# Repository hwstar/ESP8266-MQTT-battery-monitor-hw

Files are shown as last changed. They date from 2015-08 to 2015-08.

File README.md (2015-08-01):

**ESP8266-MQTT-battery-monitor-hw**
==========
This is the hardware implementation for my ESP8266-MQTT-battery-monitor project.

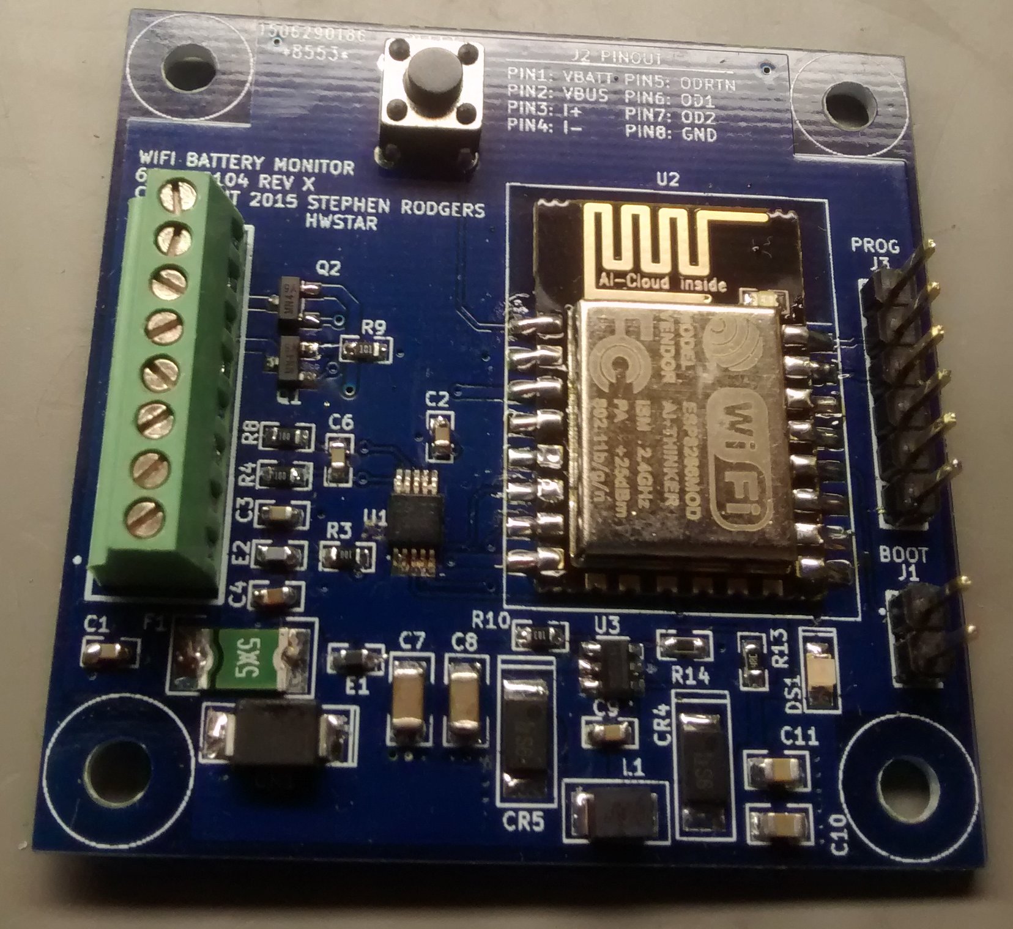
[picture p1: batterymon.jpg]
ProjectPicture


**Features:**

This board contains an ESP12 module, a Texas Instruments LMR12010X DC-DC converter and an Texas Instruments INA226 DC voltage and current monitor.
The board can be powered from any voltage from 5.5V to 16V. It is optimized to work with 12V lead acid batteries. There is transient protection
on the power input, and voltage and current inputs. There is a 1/2 amp PTC fuse on the power input.

A wide range of current shunts can be used on the differential current inputs, and the shunt
current and full scale millivolt values are programmable in the firmware. The current value is and integer, and will be negative if the battery is being discharged.

**EDA Software**

This board was designed using KICAD. 

**Board Size**

5cm x 5cm

**Firmware**

The firmware for this project can be found [here](https://github.com/hwstar/ESP8266-MQTT-battery-monitor-fw)

**LICENSE**

Creative Commons Attribution Share-Alike license. (CC-BY-SA)

**Disclaimer**

Build and use at your own risk. I will not be responsible for any damages including but not limited to: errors or omissions, loss of life, or property damage. You have been warned.

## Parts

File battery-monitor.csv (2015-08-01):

Item | Part Number | Qty | Reference(s) | Title/Description | Value on Schematic | Manufacturer | Manufacturer Part Number
1 | 800000-103 | 3 | C1,C3,C9 | CAP,0603,0.01u,25V,X7R | 0.01u | Open Market | N/A
2 | 800004-106 | 2 | C10,C11 | CAP,0805,10u,16V,X7R | 10u | Samsung | CL21B106KOQNNNE
3 | 800000-104 | 3 | C2,C4,C5 | CAP,0603,0.1u,25V,X7R | 0.1u | Open Market | N/A
4 | 800000-224 | 1 | C6 | CAP,0603,0.22u,25V,X7R | 0.22u | Open Market | N/A
5 | 800005-106 | 2 | C7,C8 | CAP,1206,10u,25V,X7R | 10u | Taiyo-Yuden | TMK316B7106KL-TD
6 | 800141-018 | 1 | CR1 | DIODE,TVS,SMB,18V | SMBJ18 | Littelfuse | SMBJ18A
7 | 800135-024 | 2 | CR2,CR3 | DIODE,DUAL,TVS,SOT23,24V,300W,CA | SM24T1G | On Semiconductor | SM24T1G
8 | 800138-101 | 2 | CR4,CR5 | DIODE,SCHOTTKY,2A,30V,M-FLAT | CMS06 | Toshiba | CMS06
9 | 800113-102 | 1 | DS1 | LED,GREEN,0805 | LEDGRN | Open Market | N/A
10 | 800040-600 | 2 | E1,E2 | FERRITE,CHIP,0603,600 OHM,500MA | FB0603 | TDK | MMZ1608S601A
11 | 800140-500 | 1 | F1 | FUSE,PTC,1812,500mA,24V | 0.5A | Tyco Electronics | MINISMDC050F-2
12 | 800116-102 | 1 | J1 | CONN,HDR,2CKT,0.1PITCH,BERGSTRIP | CONN2 | Open Market | N/A
13 | 800117-108 | 1 | J2 | CONN,TERM BLK,8CKT,0.1 PITCH | CONN8 | Open Market | N/A
14 | 800116-106 | 1 | J3 | CONN,HDR,6CKT,0.1PITCH,BERGSTRIP | CONN6 | Open Market | N/A
15 | 800139-100 | 1 | L1 | IND,1210,10uH,450mA | 10uH | TDK | NLCV32T-100K-PFR
16 | 800123-101 | 2 | Q1,Q2 | XSTR,MOSFET,N-CH,4.0A,30V,SOT-23 | DMN3112 | Diodes Inc. | DMN3112S-7
16 |  |  |  |  |  | Vishay | SI2306BDS-T1-E3
17 | 800010-102 | 5 | R1,R2,R7,R11,R12 | RES,0603,1K OHM,5% | 1K | Open Market | N/A
18 | 800010-103 | 1 | R10 | RES,0603,10K OHM,5% | 10K | Open Market | N/A
19 | 800023-309 | 1 | R13 | RES,0603,30.9K OHM,1% | 30.9K | Open Market | N/A
20 | 800023-100 | 1 | R14 | RES,0603,10.0K OHM,1% | 10.0K | Open Market | N/A
21 | 800011-221 | 1 | R15 | RES,0805,220 OHM,5% | 220 | Open Market | N/A
22 | 800010-100 | 3 | R3,R4,R8 | RES,0603,10 OHM,5% | 10 | Open Market | N/A
23 | 800010-472 | 2 | R5,R6 | RES,0603,4.7K OHM,5% | 4.7K | Open Market | N/A
24 | 800010-101 | 1 | R9 | RES,0603,100 OHM,5% | 100 | Open Market | N/A
25 | 800107-101 | 1 | S1 | SWITCH, TACT, 6MM | SW_TACT | Open Market | N/A
26 | 800137-101 | 1 | U1 | IC,MONITOR,POWER,I2C,BIDIR,10-MSOP | INA226 | Texas Instruments | INA226AIDGSR
27 | 800106-101 | 1 | U2 | MODULE,WIFI,ESP12 | ESP8266-ESP-12 | Open Market | N/A
28 | 800136-101 | 1 | U3 | IC,VREG,SWITCHING,1.6 MHZ,1A,SOT23-6 THIN | LMR12010XMKE | Texas Instruments | LMR12010XMKE/NOPB

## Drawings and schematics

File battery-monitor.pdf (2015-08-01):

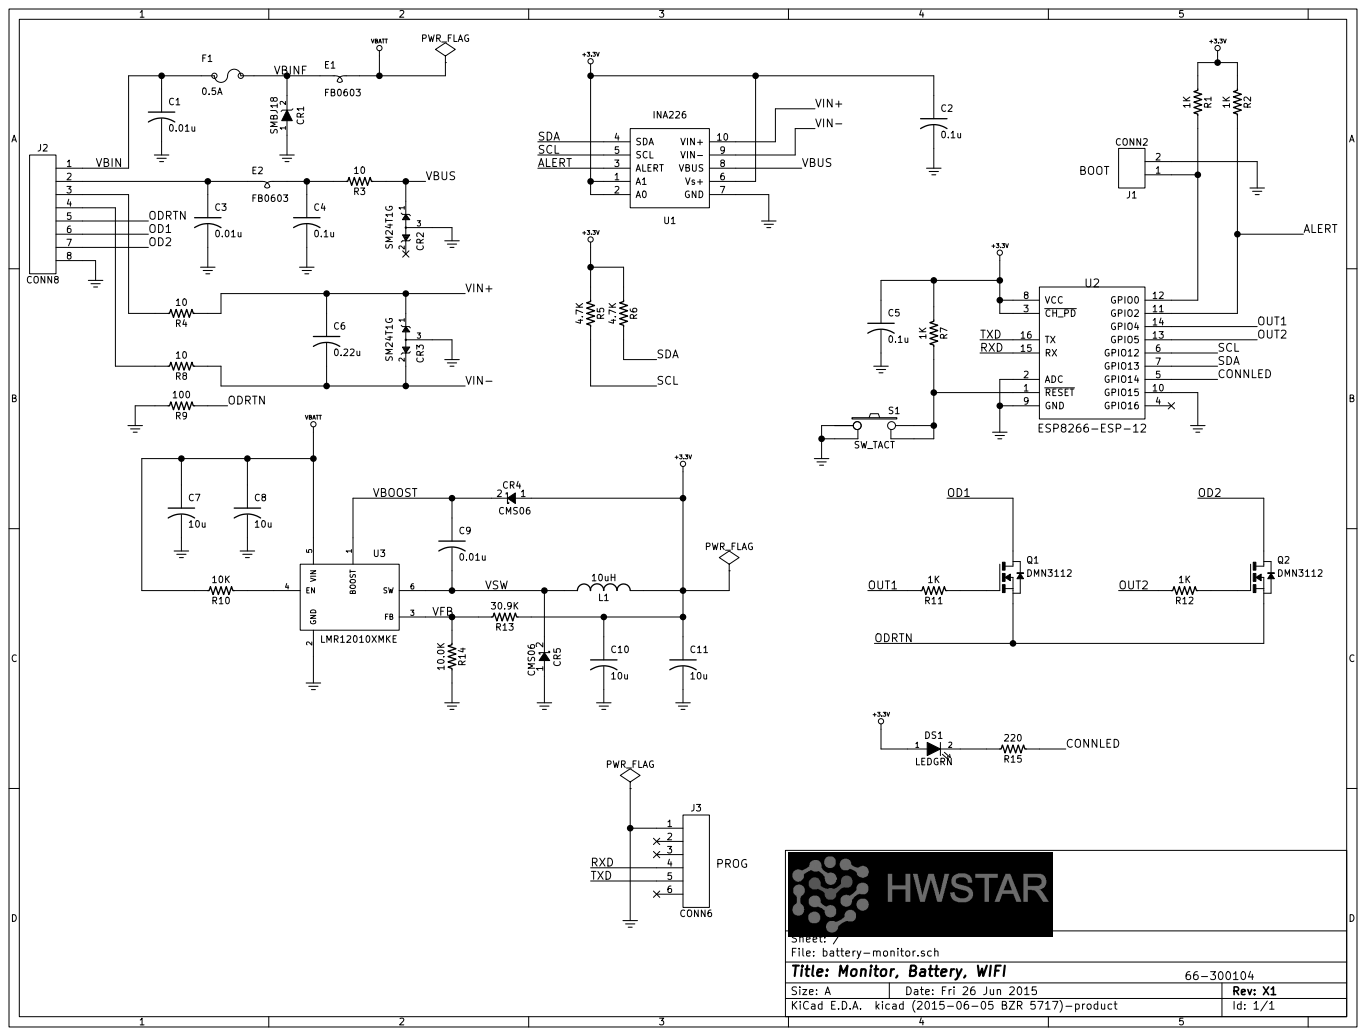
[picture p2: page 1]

Id: 1/1 Title: Monitor, Battery, WIFI

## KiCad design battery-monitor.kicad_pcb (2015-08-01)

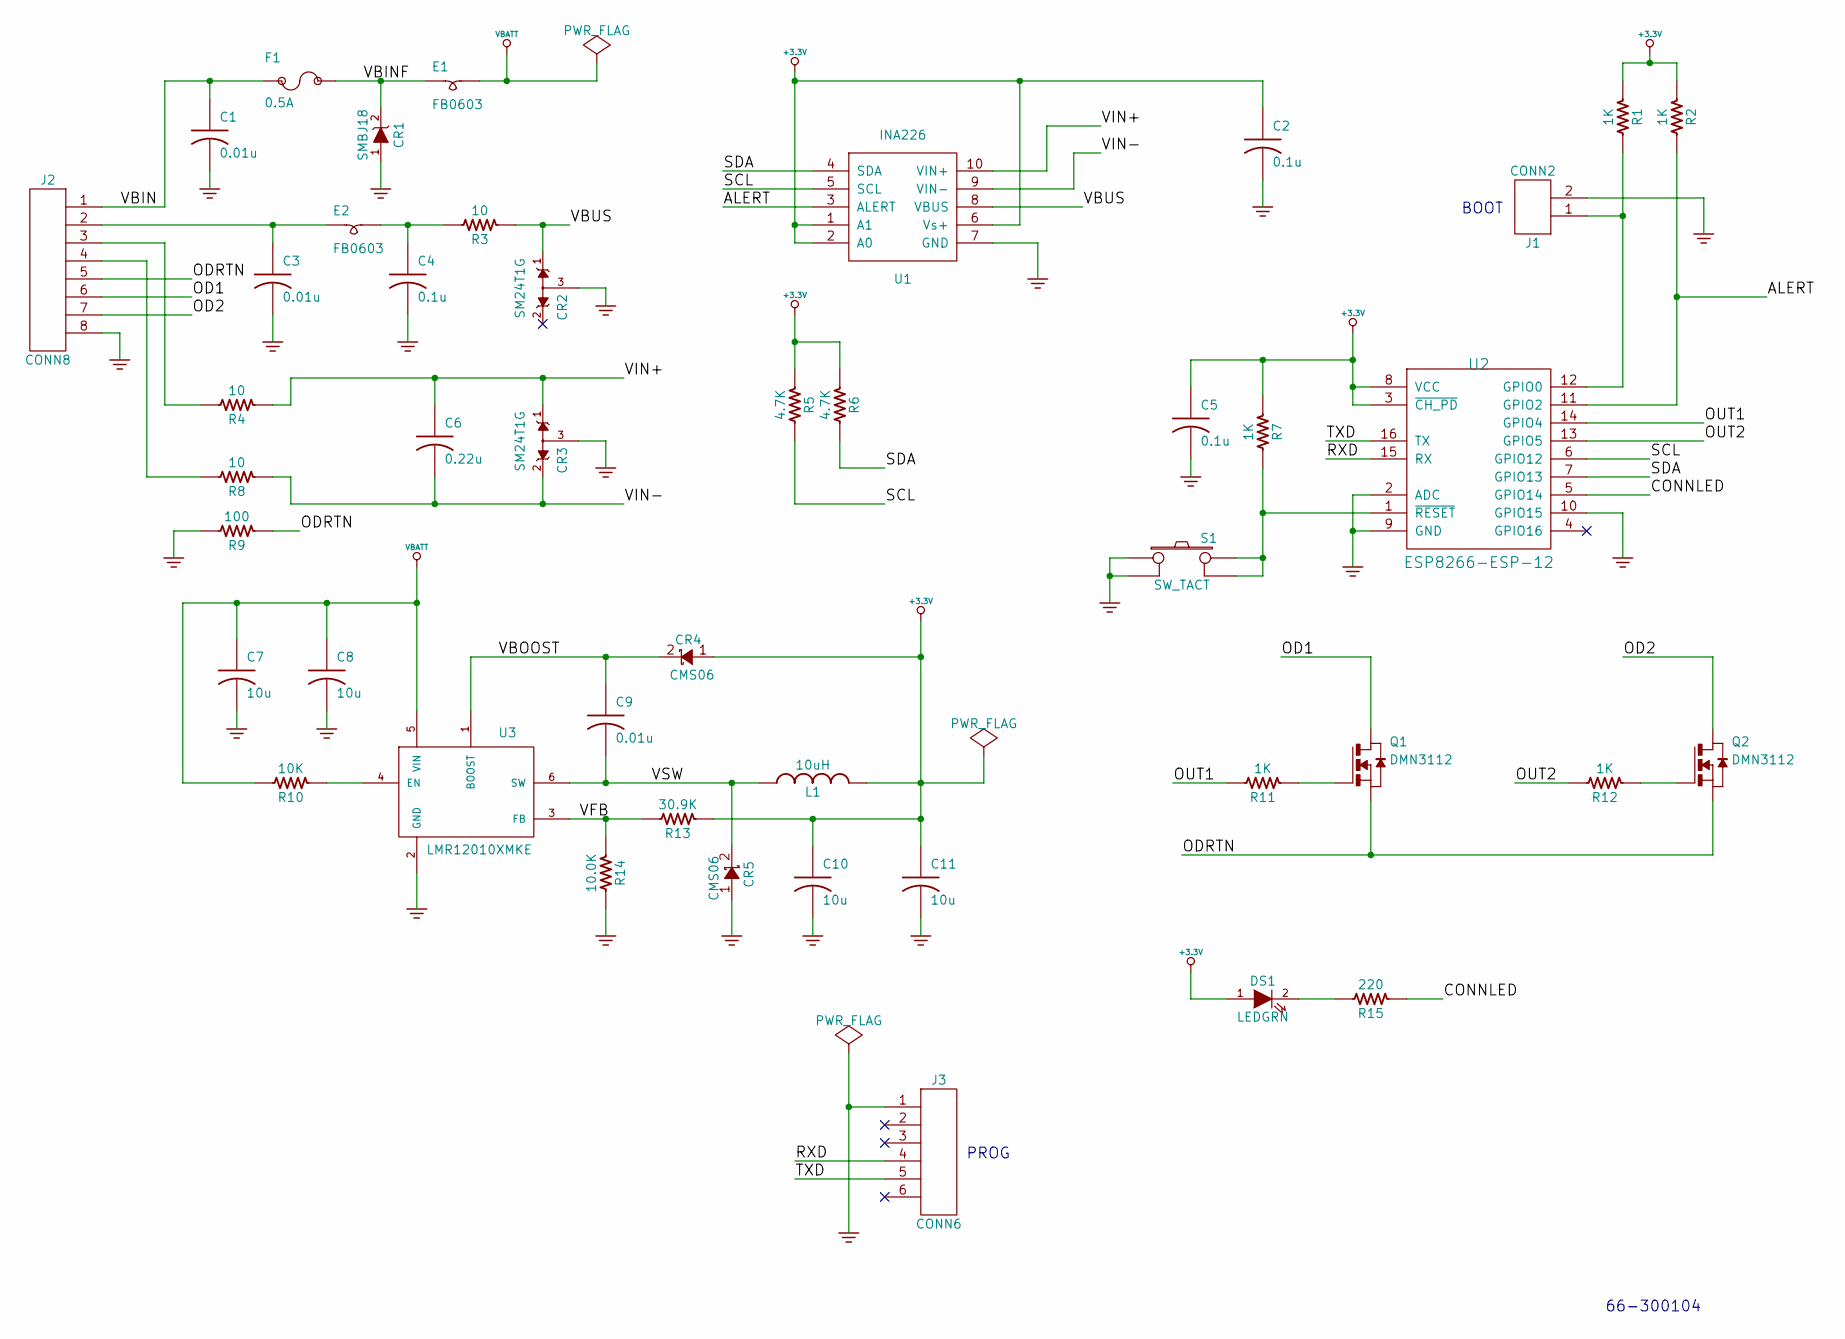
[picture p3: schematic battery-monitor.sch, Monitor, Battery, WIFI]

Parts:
C1, C3, C9: 0.01u; CC0603; PartNumber 800000-103
C2, C4, C5: 0.1u; CC0603; PartNumber 800000-104
C6: 0.22u; CC0603; PartNumber 800000-224
C7, C8: 10u; CC1206; PartNumber 800005-106
C10, C11: 10u; CC0805; PartNumber 800004-106
CR1: SMBJ18; SMB-SAR; PartNumber 800141-018
CR2, CR3: SM24T1G; SOT23-3-SAR; PartNumber 800135-024
CR4, CR5: CMS06; M-FLAT-SAR; PartNumber 800138-101
DS1: LEDGRN; LED0805; PartNumber 800113-102
E1, E2: FB0603; CC0603; PartNumber 800040-600
F1: 0.5A; MINISMD1812; PartNumber 800140-500
J1: CONN2; BERG2; PartNumber 800116-102
J2: CONN8; PHOENIX254-8; PartNumber 800117-108
J3: CONN6; BERG6; PartNumber 800116-106
L1: 10uH; IND1210; PartNumber 800139-100
Q1, Q2: DMN3112; SOT23-3-SAR; PartNumber 800123-101
R1, R2, R7, R11, R12: 1K; RC0603; PartNumber 800010-102
R3, R4, R8: 10; RC0603; PartNumber 800010-100
R5, R6: 4.7K; RC0603; PartNumber 800010-472
R9: 100; RC0603; PartNumber 800010-101
R10: 10K; RC0603; PartNumber 800010-103
R13: 30.9K; RC0603; PartNumber 800023-309
R14: 10.0K; RC0603; PartNumber 800023-100
R15: 220; RC0805; PartNumber 800011-221
S1: SW_TACT; SW_TACT_6MM; PartNumber 800107-101
U1: INA226; MSOP-10-SAR; PartNumber 800137-101
U2: ESP8266-ESP-12; ESP8266-ESP12; PartNumber 800106-101
U3: LMR12010XMKE; SOT23-6-SAR; PartNumber 800136-101

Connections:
+3.3V: C2.1, C5.1, C10.1, C11.1, CR4.1 (A), DS1.1 (A), L1.2, R1.1, R2.1, R5.1, R6.1, R7.1, R13.1, U1.1 (A1), U1.2 (A0), U1.6 (Vs+), U2.3 (~CH_PD), U2.8 (VCC)
/ALERT: R2.2, U1.3 (ALERT), U2.11 (GPIO2)
/CONNLED: R15.1, U2.5 (GPIO14)
/OD1: J2.6, Q1.3 (D)
/OD2: J2.7, Q2.3 (D)
/ODRTN: J2.5, Q1.2 (S), Q2.2 (S), R9.1
/OUT1: R11.2, U2.14 (GPIO4)
/OUT2: R12.2, U2.13 (GPIO5)
/RXD: J3.4, U2.15 (RX)
/SCL: R5.2, U1.5 (SCL), U2.6 (GPIO12)
/SDA: R6.2, U1.4 (SDA), U2.7 (GPIO13)
/TXD: J3.5, U2.16 (TX)
/VBIN: C1.1, F1.1, J2.1
/VBINF: CR1.2 (K), E1.1, F1.2
/VBOOST: C9.1, CR4.2 (K), U3.1 (BOOST)
/VBUS: CR2.1 (K1), R3.1, U1.8 (VBUS)
/VFB: R13.2, R14.1, U3.3 (FB)
/VIN+: C6.1, CR3.1 (K1), R4.1, U1.10 (VIN+)
/VIN-: C6.2, CR3.2 (K2), R8.1, U1.9 (VIN-)
/VSW: C9.2, CR5.2 (K), L1.1, U3.6 (SW)
GND: C1.2, C2.2, C3.2, C4.2, C5.2, C7.2, C8.2, C10.2, C11.2, CR1.1 (A), CR2.3 (AA), CR3.3 (AA), CR5.1 (A), J1.2, J2.8, J3.1, R9.2, R14.2, S1.1, S1.2, U1.7 (GND), U2.2 (ADC), U2.9 (GND), U2.10 (GPIO15), U3.2 (GND)
unnamed: C3.1, E2.1, J2.2
unnamed: C4.1, E2.2, R3.2
unnamed: DS1.2 (K), R15.2
unnamed: J1.1, R1.2, U2.12 (GPIO0)
unnamed: J2.3, R4.2
unnamed: J2.4, R8.2
unnamed: Q1.1 (G), R11.1
unnamed: Q2.1 (G), R12.1
unnamed: R7.2, S1.3, S1.4, U2.1 (~RESET)
unnamed: R10.1, U3.4 (EN)
VBATT: C7.1, C8.1, E1.2, R10.2, U3.5 (VIN)

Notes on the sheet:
66-300104
PROG
BOOT

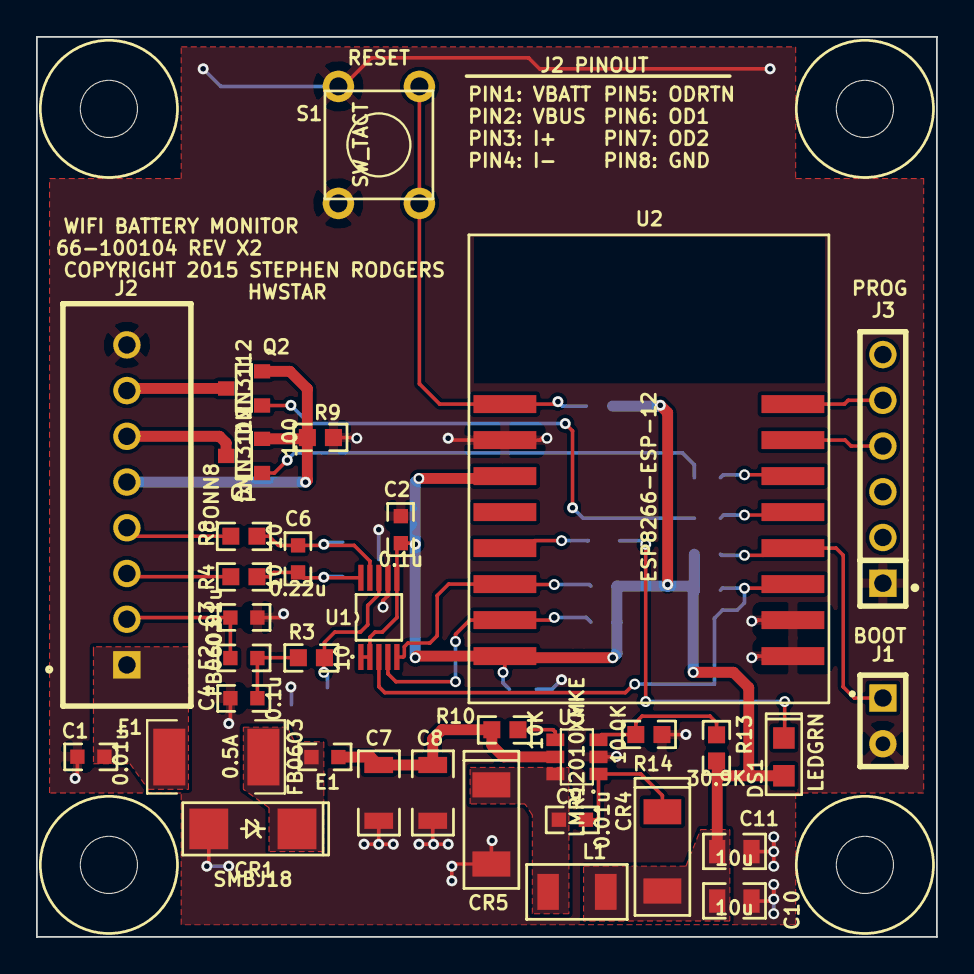
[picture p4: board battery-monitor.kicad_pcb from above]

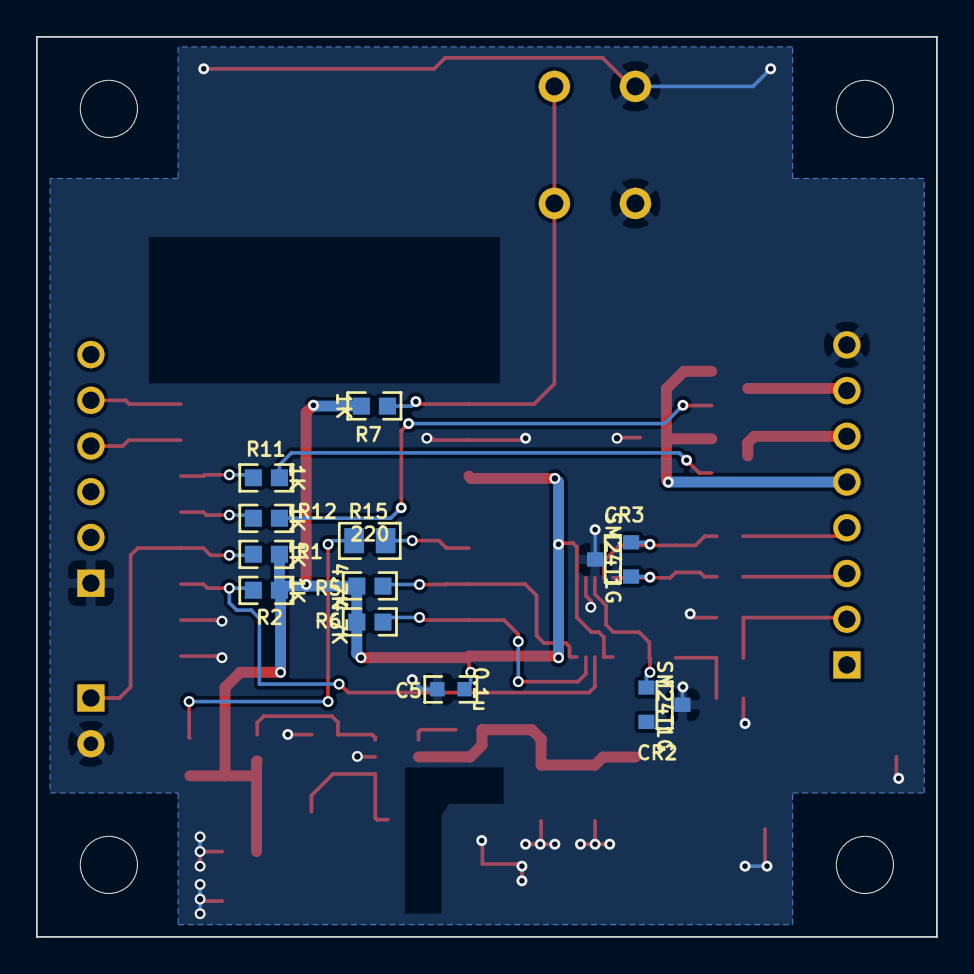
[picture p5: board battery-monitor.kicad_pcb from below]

Board: 2 copper layers, 50.0 x 50.0 mm, 49 parts (11 on the bottom side), 32 nets.

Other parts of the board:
MTG-HOLE-125-RING-300, MTG-HOLE-125-RING-300#2, MTG-HOLE-125-RING-300#3, MTG-HOLE-125-RING-300#4: VAL**; MTG-HOLE-125-RING-300

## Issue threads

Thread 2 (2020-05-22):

Cool project

Curtis777, 2020-05-22:
I love your project this is exactly what Iam looking for...
Is there any way to get a pcb? I don't know anybody who makes one pcb :-(

hwstar, 2020-05-23:
I'm out of PCB's, and there are a few improvements to be made to the layout to fix some issues.

Closed 2020-05-23.

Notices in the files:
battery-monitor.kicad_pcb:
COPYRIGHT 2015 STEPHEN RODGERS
